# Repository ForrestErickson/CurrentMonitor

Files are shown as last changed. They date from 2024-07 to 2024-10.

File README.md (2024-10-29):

# Current Monitor
Connect in line with power supply to load and measure voltage drop across a selectable resistance.  
A project motivated in part to learn how to use JLCPCB to KiCAD plug-in.

# Online Viewer

* [Schematic Link](https://kicanvas.org/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)

* [PCB Link](https://kicanvas.org/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)

## Credits  
JLC-Plugin-for-KiCad schematic symbol and PCB footprint and 3D model from:  https://github.com/Springer-Electronics/JLC2KiCad_lib  
JLC-Plugin-for-KiCad schematic Fabrication from:  https://github.com/bennymeg/JLC-Plugin-for-KiCad  
KiCad-DesignRules method from: https://github.com/labtroll/KiCad-DesignRules?tab=readme-ov-file  

## License and Warranty
License: This project and files are dedicated and released to the public domain.  
Warranty: This project and files are designed to kill you and render the earth uninhabitible, however they not guarenteed to do so.

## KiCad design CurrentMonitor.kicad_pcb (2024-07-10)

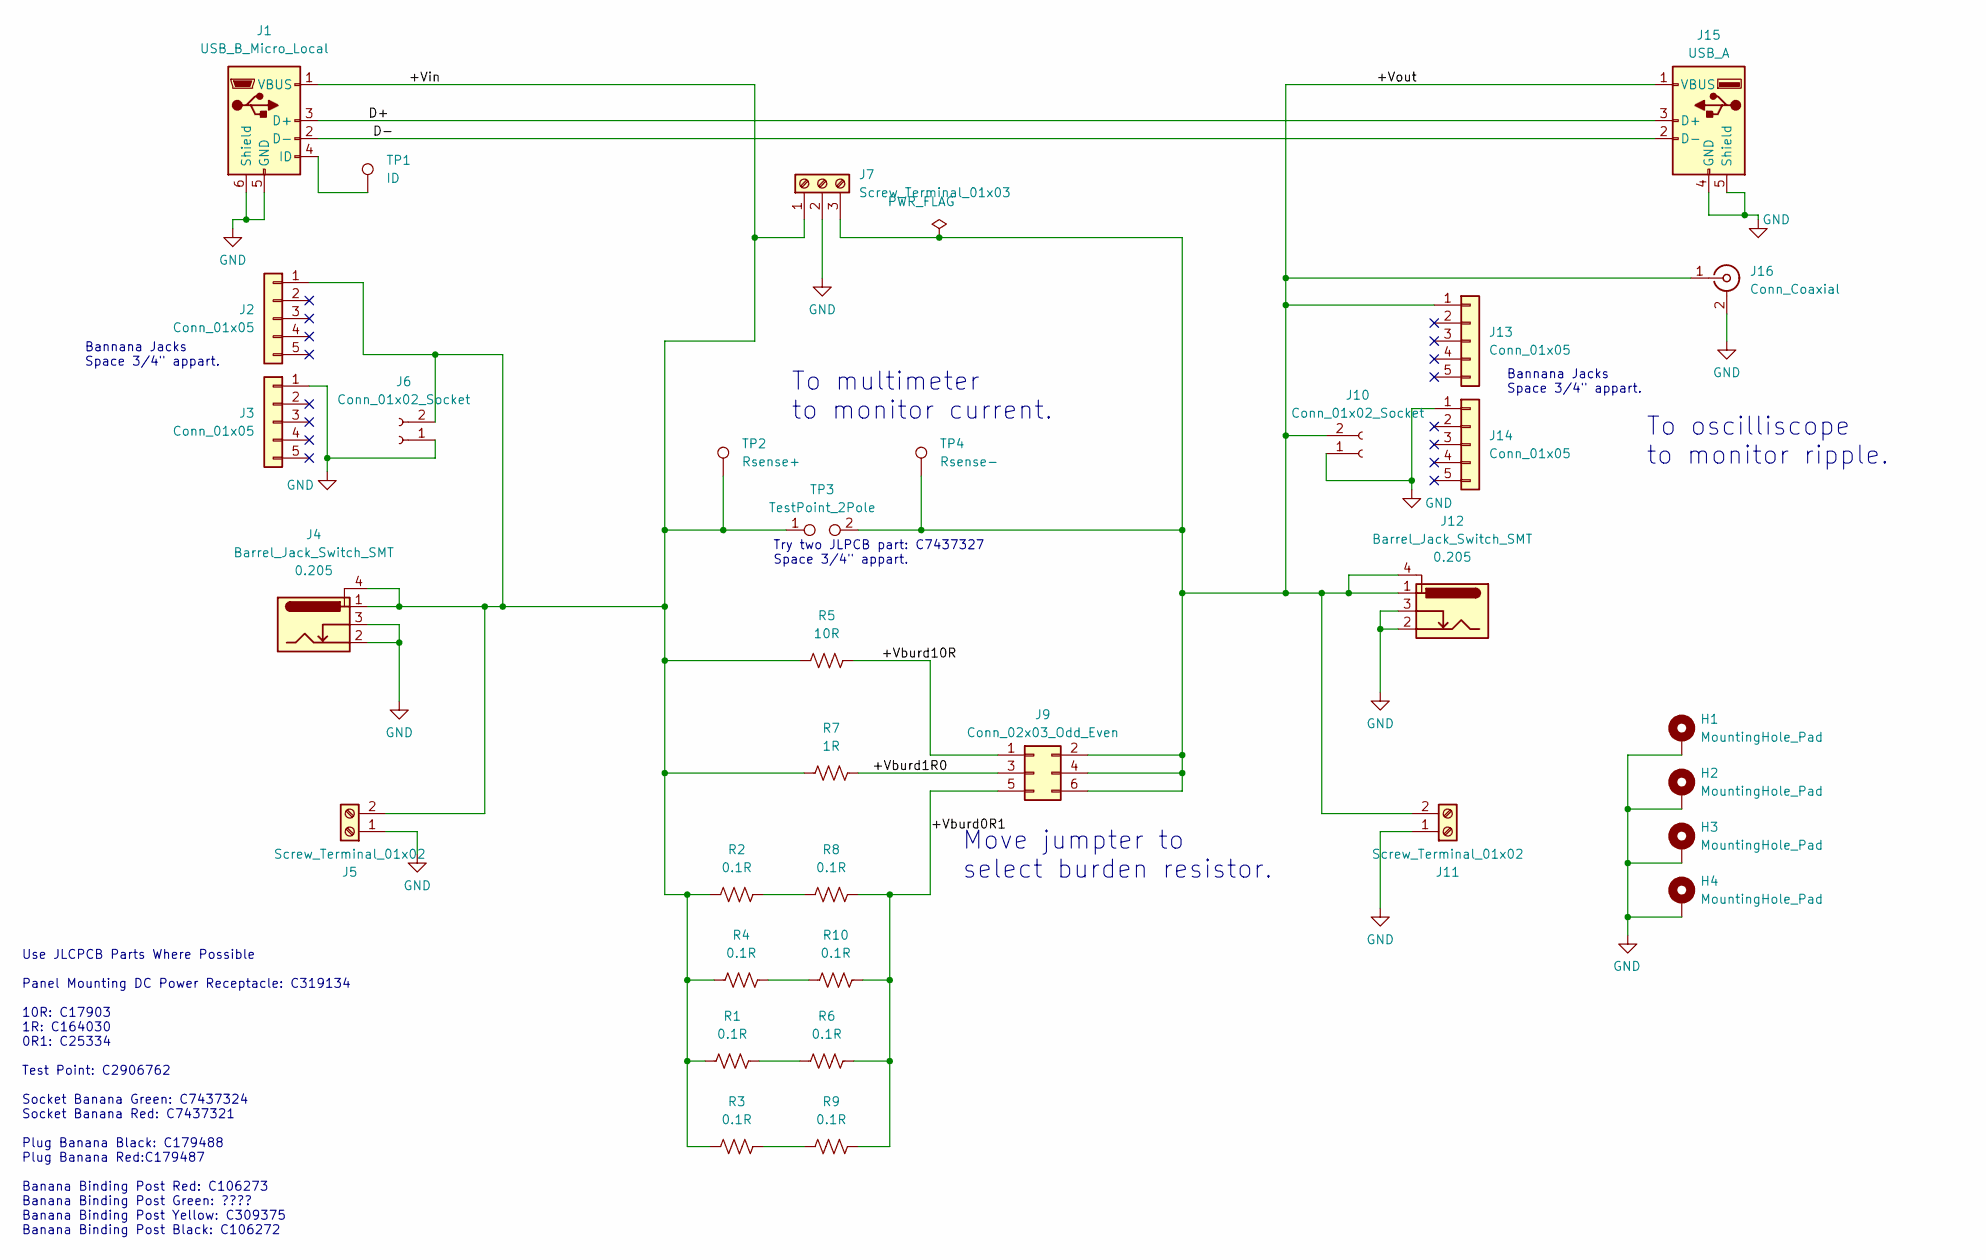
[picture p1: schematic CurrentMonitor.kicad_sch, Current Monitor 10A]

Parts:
H1, H2, H3, H4: MountingHole_Pad; MountingHole_3.5mm_Pad_Via
J1: USB_B_Micro_Local; USB_Micro-B_Amphenol_10118194_Horizontal
J2, J3, J13, J14: Conn_01x05; Banana_Cliff_FCR7350x_S16N-PC_Horizontal_5Pins
J4, J12: Barrel_Jack_Switch_SMT; BarrelJack_CLIFF_FC681465S_SMT_Horizontal; MPN DC-005-5A-2.0-SMT / 54-00164
J5, J11: Screw_Terminal_01x02; TerminalBlock_Phoenix_MKDS-1,5-2_1x02_P5.00mm_Horizontal
J6, J10: Conn_01x02_Socket; Banana_Jack_2Pin
J7: Screw_Terminal_01x03; TerminalBlock_Phoenix_MKDS-1,5-3_1x03_P5.00mm_Horizontal
J9: Conn_02x03_Odd_Even; PinHeader_2x03_P2.54mm_Vertical
J15: USB_A; USB_A_JLCPCB_C3038692_Horizontal
J16: Conn_Coaxial; BNC_Amphenol_B6252HB-NPP3G-50_Horizontal
R1, R2, R3, R4, R6, R8, R9, R10: 0.1R; R_1206_3216Metric_Pad1.30x1.75mm_HandSolder
R5: 10R; R_1206_3216Metric_Pad1.30x1.75mm_HandSolder
R7: 1R; R_1206_3216Metric_Pad1.30x1.75mm_HandSolder
TP1: ID; TestPoint_Loop_D2.50mm_Drill1.0mm
TP2: Rsense+; TestPoint_Loop_D2.50mm_Drill1.0mm
TP3: TestPoint_2Pole; Banana_Jack_2Pin
TP4: Rsense-; TestPoint_Loop_D2.50mm_Drill1.0mm

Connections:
/+Vburd0R1: J9.5, R6.2, R8.2, R9.2, R10.2
/+Vburd1R0: J9.3, R7.2
/+Vburd10R: J9.1, R5.2
/+Vin: J1.1 (VBUS), J2.1, J4.1, J4.4, J5.2, J6.2, J7.1, R1.1, R2.1, R3.1, R4.1, R5.1, R7.1, TP2.1, TP3.1
/+Vout: J7.3, J9.2, J9.4, J9.6, J10.2, J11.2, J12.1, J12.4, J13.1, J15.1 (VBUS), J16.1 (In), TP3.2, TP4.1
/D+: J1.3 (D+), J15.3 (D+)
/D-: J1.2 (D-), J15.2 (D-)
GND: H1.1, H2.1, H3.1, H4.1, J1.5 (GND), J1.6 (Shield), J3.1, J4.2, J4.3, J5.1, J6.1, J7.2, J10.1, J11.1, J12.2, J12.3, J14.1, J15.4 (GND), J15.5 (Shield), J16.2 (Ext)
unnamed: J1.4 (ID), TP1.1
unnamed: R1.2, R6.1
unnamed: R2.2, R8.1
unnamed: R3.2, R9.1
unnamed: R4.2, R10.1

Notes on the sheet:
Use JLCPCB Parts Where Possible Panel Mounting DC Power Receptacle: C319134 10R: C17903 1R: C164030 0R1: C25334 Test Point: C2906762 Socket Banana Green: C7437324 Socket Banana Red: C7437321 Plug Banana Black: C179488 Plug Banana Red:C179487 Banana Binding Post Red: C106273 Banana Binding Post Gree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
To multimeter to monitor current.
Try two JLPCB part: C7437327 Space 3/4" appart.
Bannana Jacks Space 3/4" appart.
Move jumpter to select burden resistor.
To oscilliscope to monitor ripple.

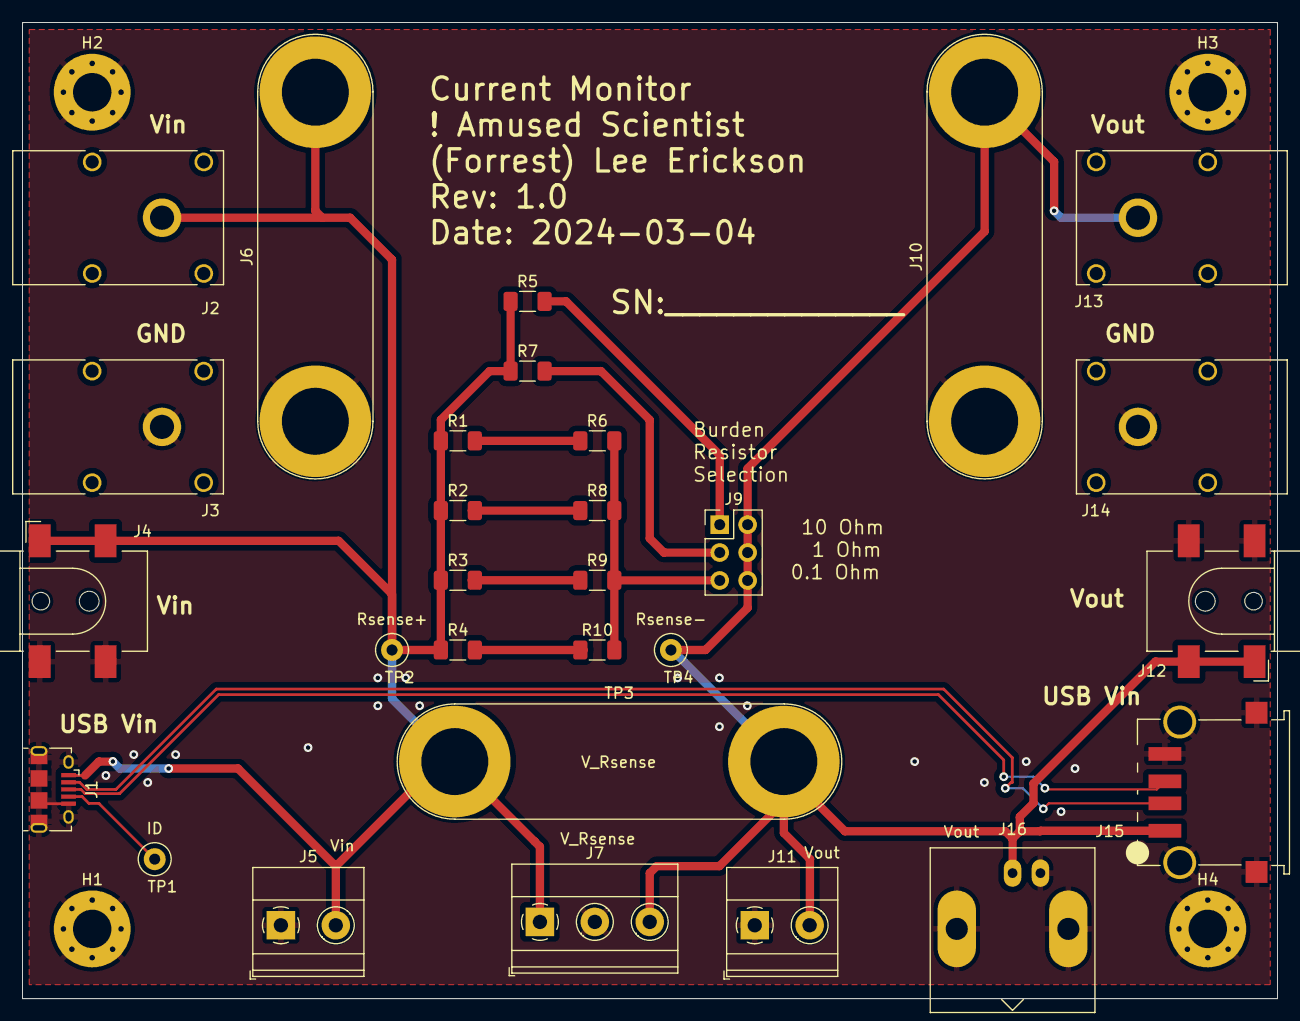
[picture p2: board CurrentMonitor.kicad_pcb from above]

Board: 2 copper layers, 114.3 x 88.9 mm, 33 parts (0 on the bottom side), 13 nets.

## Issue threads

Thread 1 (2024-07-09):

Try using SnapEDA Footprints

ForrestErickson, 2024-07-09:
Learned about from here:
https://forum.kicad.info/t/need-library-of-esp32-dev-kit-c-v2-being-new-need-help-searching/37937/4

Here is an example of a Micro USB
https://www.snapeda.com/parts/10118194-0001LF/Amphenol%20ICC/view-part/?ref=search&t=USB%20micro

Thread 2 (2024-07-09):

Make USB A Footprint

ForrestErickson, 2024-07-09:
JLCPCB part:
https://jlcpcb.com/partdetail/3591750-KH_AF90CB_136SMT/C3038692
Manufacturer: Shenzhen Kinghelm Elec
MFR.Part #: KH-AF90CB-13.6SMT
JLCPCB Part #: C3038692
Package: SMD
Description: 1.5A 1 Sink board 4P Female Type-A SMD USB Connectors ROHS

Drawing:
https://wmsc.lcsc.com/wmsc/upload/file/pdf/v2/lcsc/2206161801_Shenzhen-Kinghelm-Elec-KH-AF90CB-13-6SMT_C3038692.pdf
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

ForrestErickson, 2024-07-10:
Made a part and put in library and in PCB.
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

Closed 2024-07-10.

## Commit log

2024-03-04 Initial commit.
    [CurrentMonitor.kicad_pcb, CurrentMonitor.kicad_sch]
2024-03-04 Add design rule check custom check.
    [CurrentMonitor.kicad_pcb, CurrentMonitor.kicad_sch]
2024-03-04 Add more JLCPCB parts, banana jacks and more.
    [CurrentMonitor.kicad_sch]
2024-05-25 Add USB connectors, BNC for oscilliscope monitor.
    [CurrentMonitor.kicad_sch]
2024-05-27 Initical placement of PCB components and edges. Still need USB parts.
    [CurrentMonitor.kicad_pcb, CurrentMonitor.kicad_sch]
2024-05-27 Add another bananna jack option. Get 3D foot prints working for Barrel Jack.
    [CurrentMonitor.kicad_pcb, CurrentMonitor.kicad_sch]
2024-07-09 Update with USB type A footprint. Update footprint of Barrel jack, mounting holes and bannana jacks. No ERC errors.
    [CurrentMonitor.kicad_pcb, CurrentMonitor.kicad_sch]
2024-07-10 Route copper on PCB.
    [CurrentMonitor.kicad_pcb, CurrentMonitor.kicad_sch]
2024-10-29 Update README.md
    Add to the README.md the KiCanvas links for Schematic and PCB.

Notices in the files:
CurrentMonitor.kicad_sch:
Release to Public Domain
